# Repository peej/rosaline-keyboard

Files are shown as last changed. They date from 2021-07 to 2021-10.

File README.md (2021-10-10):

# Rosaline - Through-hole 40% keyboard PCB for 60% cases

Rosaline is a 40% keyboard PCB using through-hole components for that visible component aesthetic.

The goal of this project is to build an all through-hole component 40% PCB that fits in a standard 60% tray mount case.

Inspired by the [Plaid](https://github.com/hsgw/plaid) and the [Romeo](https://github.com/coseyfannitutti/romeo).

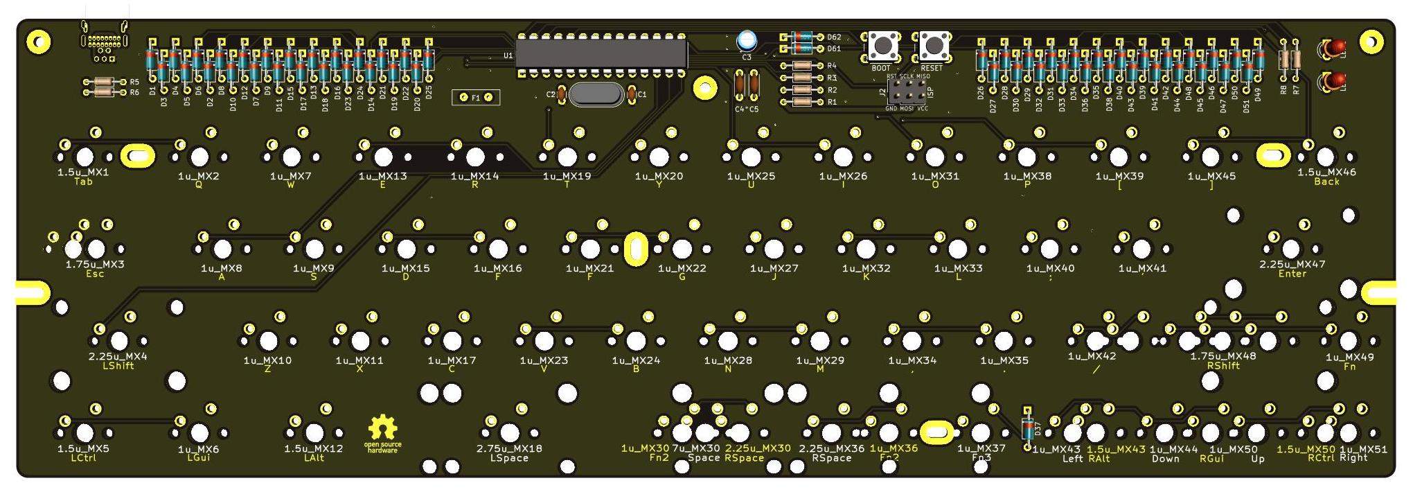
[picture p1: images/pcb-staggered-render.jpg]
PCB staggered render


* Designed to be easy to build with minimal soldering experience.
* All through-hole components, no SMD soldering required.
* Get that visible component aesthetic in a standard 60% tray-mount case.
* Staggered and ortholinear varieties.
* Supports both USB Mini and USB-C.

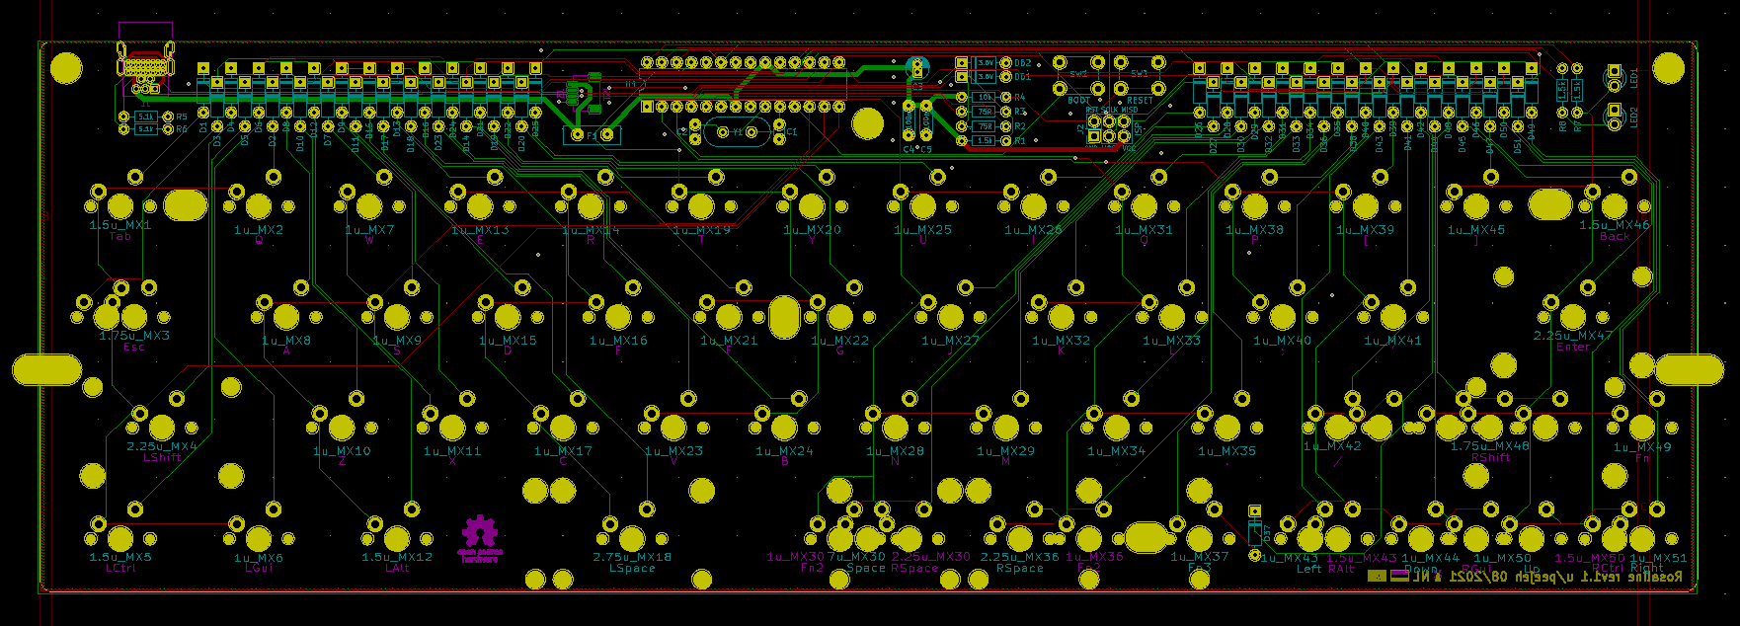
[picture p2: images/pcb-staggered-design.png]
PCB staggered design


The layout is a number row-less 60% layout with split spacebar or 7u bottom row and split right shift. An arrow cluster layout is also supported by moving the right shift.

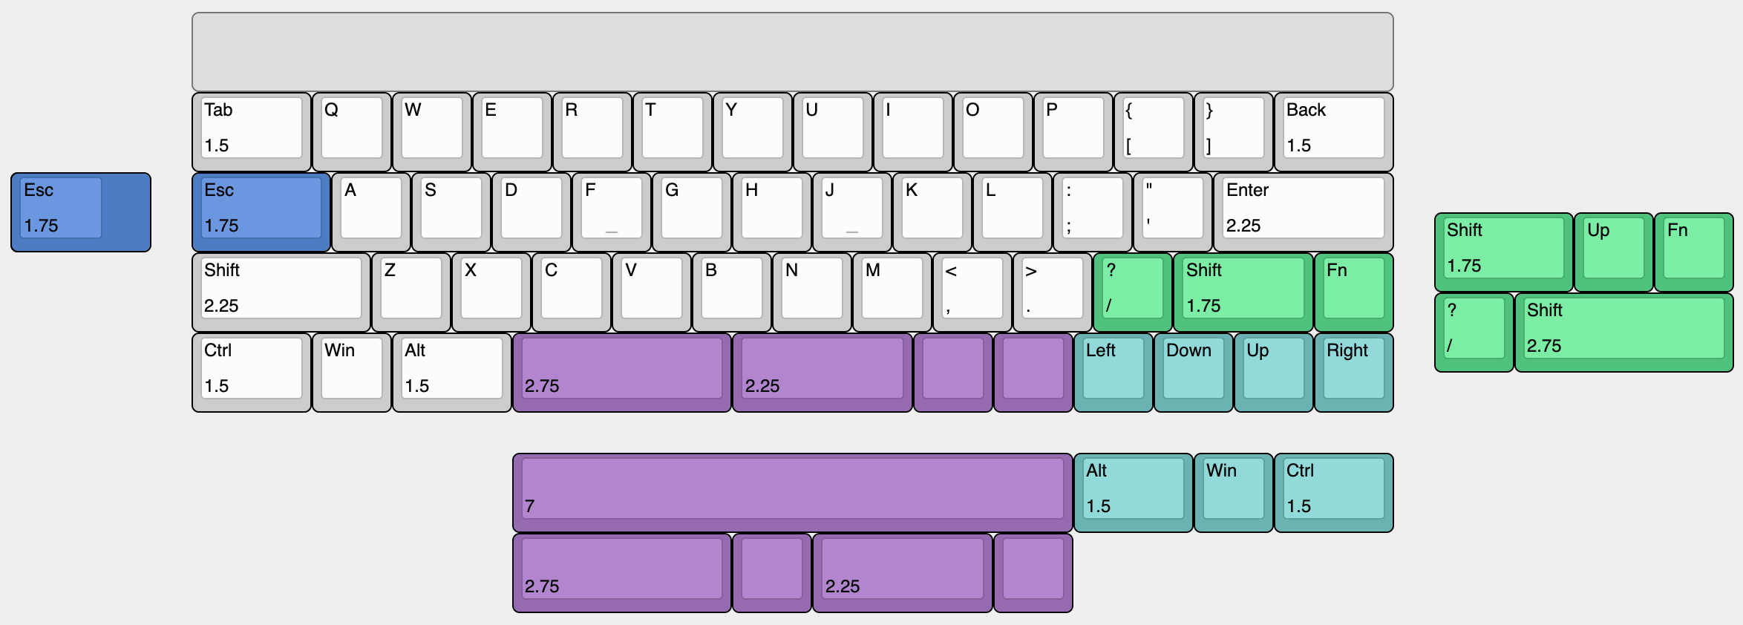
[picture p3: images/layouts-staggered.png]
Supported staggered layouts


# Ordering parts

PCBs can be manufactuered by a variety of online PCB fabricators. You can use [PCBShopper](https://pcbshopper.com/) to search for the best price.

# Construction

Solder all the components onto the top side of the PCB except the USB connector which should be on the back of the board. Leave the larger components until last so that the board will lie flat upsidedown while you solder the resistors and capacitors.

Take care to put the correct value resistors and capacitors in the correct places, the values are written on the silkmask along with the component reference. If you are unsure about the value of a resistor, check it with a multimeter.

Ensure that polarised components (diodes, LEDs, electrolytic capacitor (C3), IC socket) are in the correct orientation. The square pad is for the negative side of the component; for a diode this means the side with the black stripe; for LEDs and C3 the short leg is the cathode and goes in the square pad.

# Firmware

Firmware has not been merged into QMK upstream as of yet.

## Matrix information

If you are building your own firmware, the following matrix information will be useful to you:

| Configuration | Value |
|---|---|
| MATRIX_ROWS | 7 |
| MATRIX_COLS | 8 |
| MATRIX_ROW_PINS | C0, B5, B4, B3, B2, B1, C3 |
| MATRIX_COL_PINS | B0, D7, D6, C2, D4, D1, D0, C1 |
| DIODE_DIRECTION | COL2ROW |

# Component cover

Cut a piece of 2mm thick acrylic to size (285x19mm) and drill 3 m2 holes for the standoffs. Use the PCB as a guide for the hole positions.

Affix the 3 standoffs to the PCB with screws from underneath the PCB. Use the remaining 3 screws to attach the acrylic to the top of the standoffs.

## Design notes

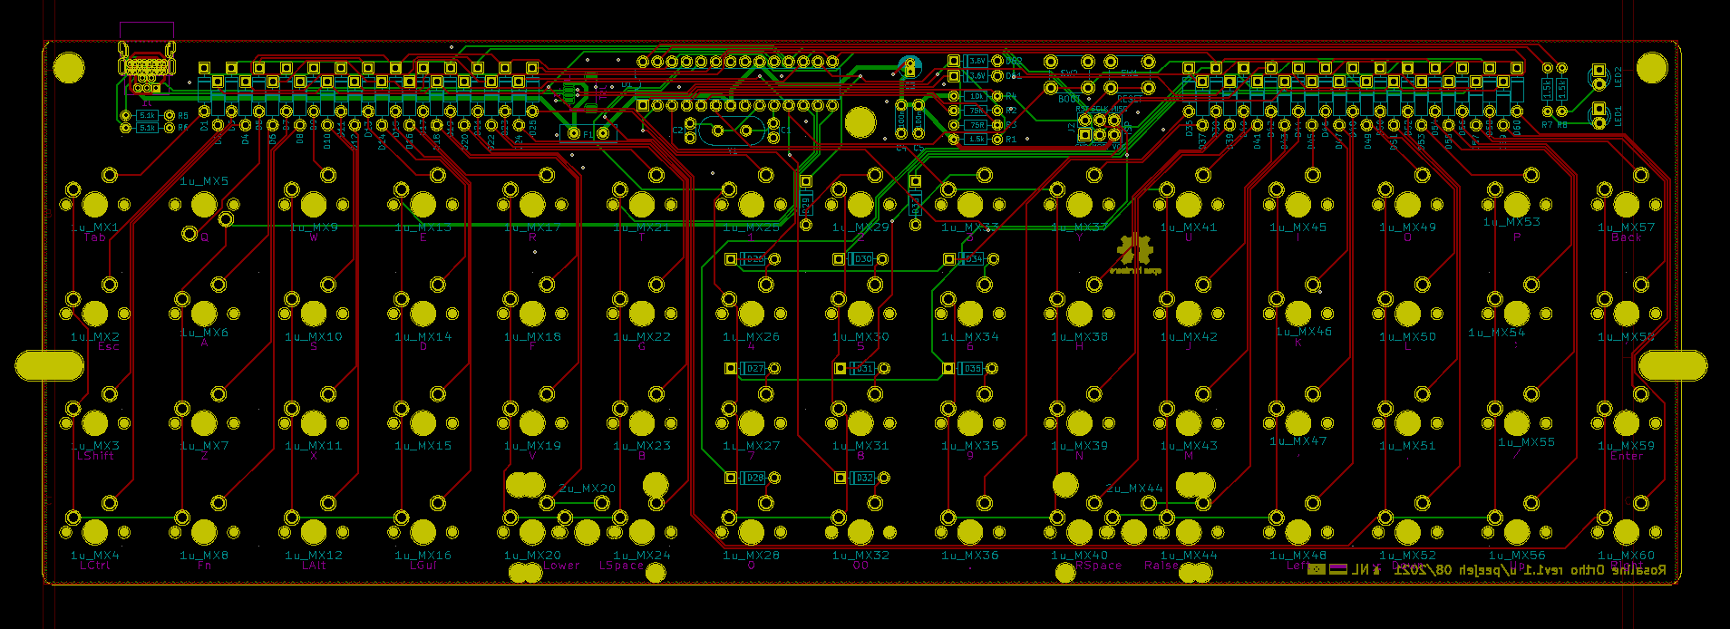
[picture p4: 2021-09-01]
images/pcb-ortho-design.png

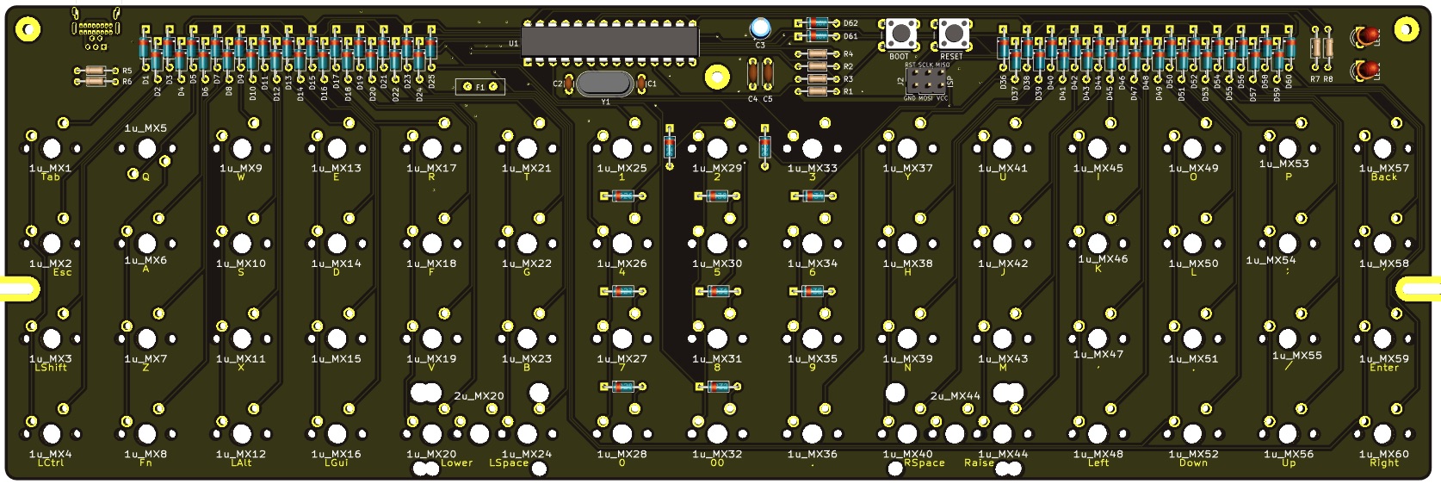
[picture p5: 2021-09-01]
images/pcb-ortho-render.jpg

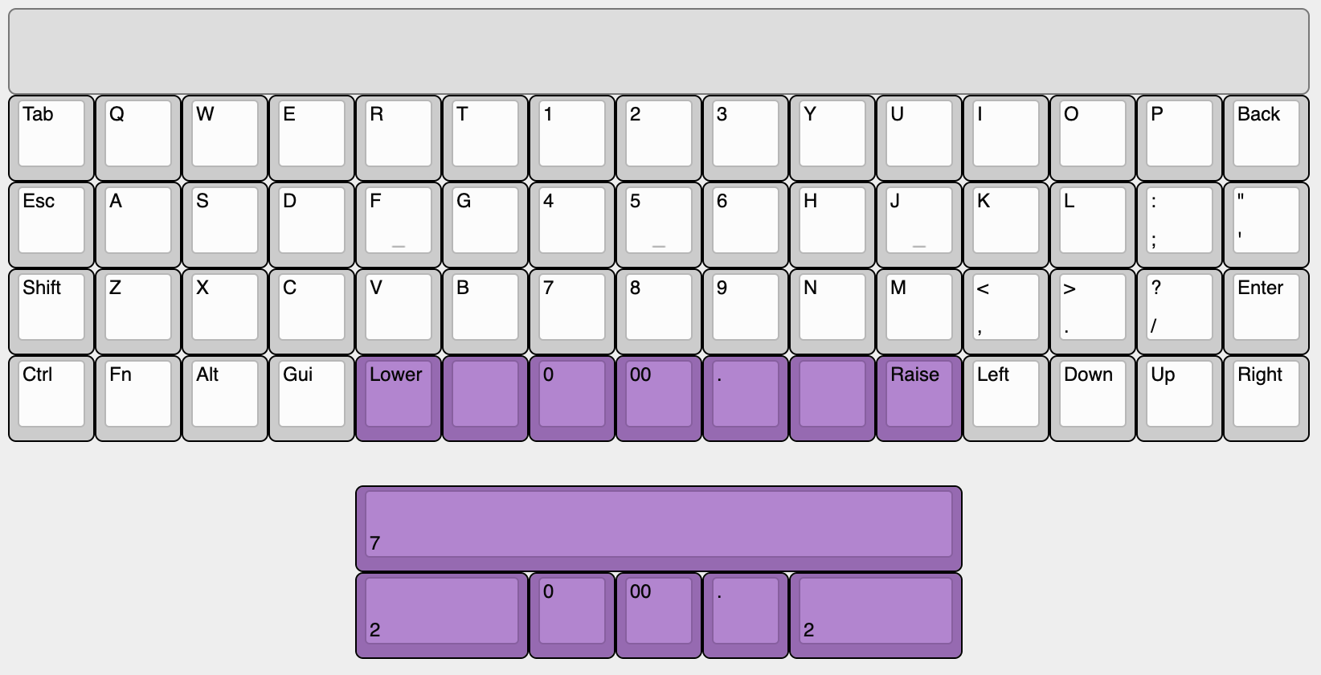
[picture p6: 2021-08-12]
images/layouts-ortho.png

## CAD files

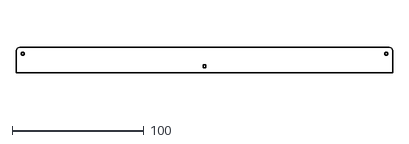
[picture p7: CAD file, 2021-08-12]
cover/cover.dxf
285.3 x 19.1

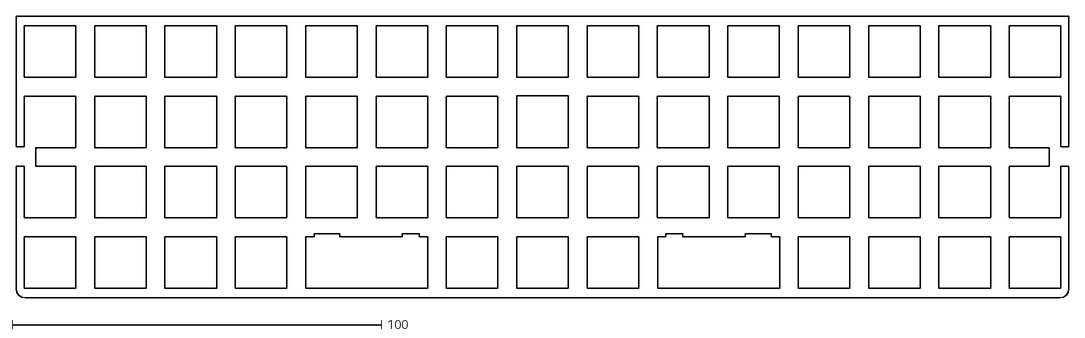
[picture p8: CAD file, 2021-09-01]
plate/plate-ortho.dxf
285.0 x 76.2

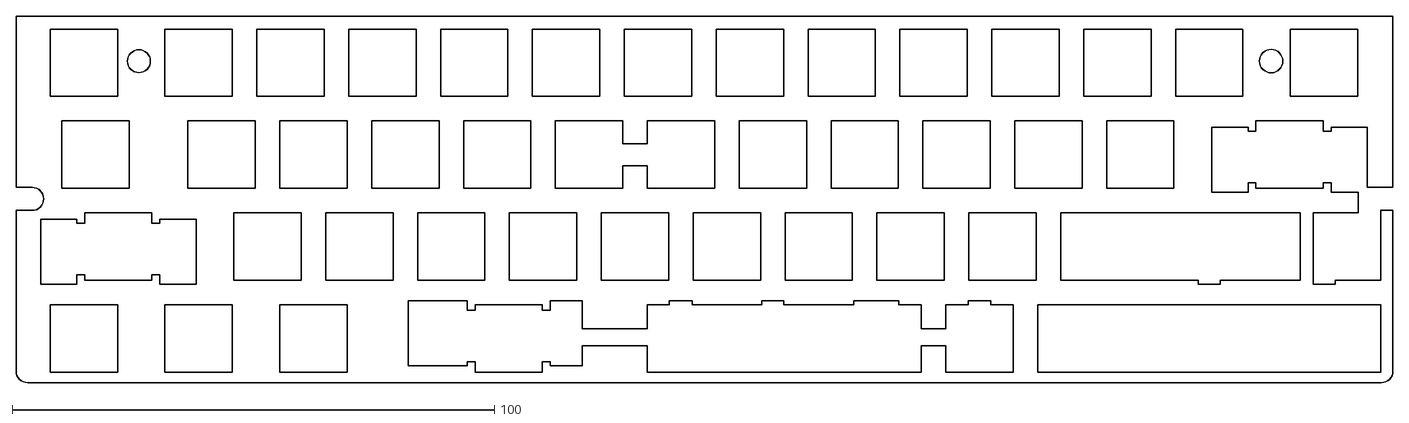
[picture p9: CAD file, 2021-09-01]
plate/plate.dxf
285.5 x 76.0

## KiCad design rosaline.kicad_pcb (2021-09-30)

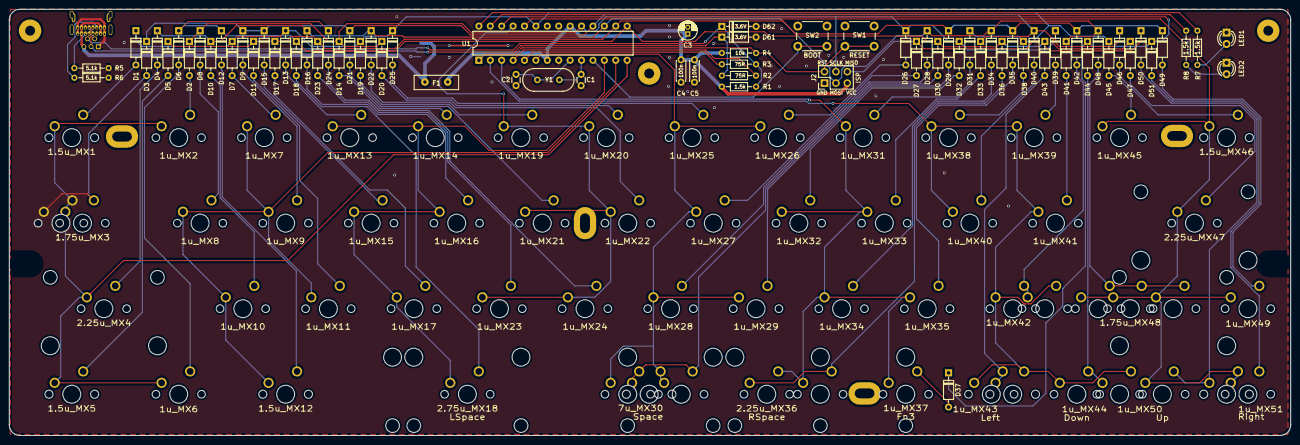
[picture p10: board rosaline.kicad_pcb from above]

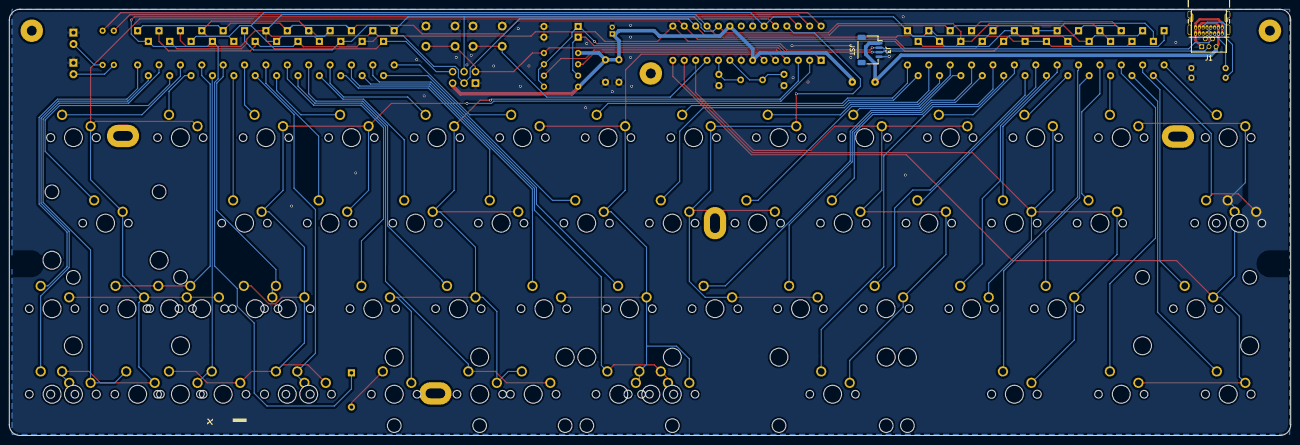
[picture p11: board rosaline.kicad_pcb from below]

Board: 2 copper layers, 285.4 x 94.9 mm, 148 parts (3 on the bottom side), 83 nets.

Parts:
1.5u_MX1: Tab; MX_PCB_150H
1.5u_MX5: LCtrl; MX_PCB_150H
1.5u_MX12: LAlt; MX_PCB_150H
1.5u_MX43: RAlt; MX_PCB_150H
1.5u_MX46: Back; MX_PCB_150H
1.5u_MX50: RCtrl; MX_PCB_150H
1.75u_MX3: Esc; MX_PCB_175H
1.75u_MX42, 1.75u_MX48: RShift; MX_PCB_175H
1u2_MX44: RGui; MX
1u_MX2: Q; MX
1u_MX6: LGui; MX
1u_MX7: W; MX
1u_MX8: A; MX
1u_MX9: S; MX
1u_MX10: Z; MX
1u_MX11: X; MX
1u_MX13: E; MX
1u_MX14: R; MX
1u_MX15: D; MX
1u_MX16, 1u_MX21: F; MX
1u_MX17: C; MX
1u_MX19: T; MX
1u_MX20: Y; MX
1u_MX22: G; MX
1u_MX23: V; MX
1u_MX24: B; MX
1u_MX25: U; MX
1u_MX26: I; MX
1u_MX27: J; MX
1u_MX28: N; MX
1u_MX29: M; MX
1u_MX30, 1u_MX36: Fn2; MX
1u_MX31: O; MX
1u_MX32: K; MX
1u_MX33: L; MX
1u_MX34: ,; MX
1u_MX35: .; MX
1u_MX37: Fn3; MX
1u_MX38: P; MX
1u_MX39: [; MX
1u_MX40: ;; MX
1u_MX41: '; MX
1u_MX42: /; MX
1u_MX43: Left; MX
1u_MX44: Down; MX
1u_MX45: ]; MX
1u_MX48, 1u_MX50: Up; MX
1u_MX49: Fn; MX
1u_MX51: Right; MX
2.25u_MX4: LShift; MX_PCB_225H
2.25u_MX30, 2.25u_MX36: RSpace; MX_PCB_225B
2.25u_MX47: Enter; MX_PCB_225H
2.75u_MX18: LSpace; MX_PCB_275B
2.75u_MX48: RShift; MX_PCB_275H
7u_MX30: Space; MX_PCB_700H
C1, C2: 22p; C_Disc_D3.0mm_W1.6mm_P2.50mm
C3: 4.7u; CP_Radial_D4.0mm_P1.50mm
C4, C5: 100n; C_Disc_D4.3mm_W1.9mm_P5.00mm
D1, D2, D3, D4, D5, D6, D7, D8, D9, D10, D11, D12, D13, D14, D15, D16, D17, D18, D19, D20, D21, D22, D23, D24, D25, D26, D27, D28, D29, D30, D31, D32, D33, D34, D35, D36, D37, D38, D39, D40, D41, D42, D43, D44, D45, D46, D47, D48, D49, D50, D51: 1N4148; D_DO-35_SOD27_P7.62mm_Horizontal
D61, D62: 3.6V; D_DO-35_SOD27_P7.62mm_Horizontal
F1: 100mA; Fuse_Bourns_MF-RHT100
Flags: flags; Flags
H1, H2, H3: M2; MountingHole_M2
H4, H9: M2; MountingSlot_M2
H5, H6, H7, H8: M2; MountingFlex_M2
J1: USB; USB_Hybrid_THT
J2: AVR_ISP_6; PinHeader_2x03_P2.54mm_Vertical
J3: JST; JST_SH_SM04B-SRSS-TB_1x04-1MP_P1.00mm_Horizontal
LED1: RED; LED_D3.0mm
LED2: GREEN; LED_D3.0mm
OSHW: OSHW-Logo_7.5x8mm_Copper
R1, R7, R8: 1.5k; R_Axial_DIN0204_L3.6mm_D1.6mm_P7.62mm_Horizontal
R2, R3: 75R; R_Axial_DIN0204_L3.6mm_D1.6mm_P7.62mm_Horizontal
R4: 10k; R_Axial_DIN0204_L3.6mm_D1.6mm_P7.62mm_Horizontal
R5, R6: 5.1k; R_Axial_DIN0204_L3.6mm_D1.6mm_P7.62mm_Horizontal
SW1: RESET; SW_PUSH_6mm
SW2: BOOT; SW_PUSH_6mm
U1: ATMEGA328-PU; DIP-28_W7.62mm
Y1: 16MHz; Crystal_HC49-4H_Vertical
stepped_MX3: Esc; MX

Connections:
+5V: C3.1, C4.1, C5.1, F1.2, J2.5, R1.2, R4.1, U1.7, U1.20
/COL0: 1.5u_MX1.2, 1.5u_MX5.2, 1.75u_MX3.2, 1u_MX2.2, 1u_MX6.2, 2.25u_MX4.2, U1.14, stepped_MX3.1
/COL1: 1.5u_MX12.2, 1u_MX7.2, 1u_MX8.2, 1u_MX9.2, 1u_MX10.2, 1u_MX11.2, U1.13
/COL2: 1u_MX13.2, 1u_MX14.2, 1u_MX15.2, 1u_MX16.2, 1u_MX17.2, 2.75u_MX18.2, U1.12
/COL3: 1u_MX19.2, 1u_MX20.2, 1u_MX21.2, 1u_MX22.2, 1u_MX23.2, 1u_MX24.2, U1.25
/COL4: 1u_MX25.2, 1u_MX26.2, 1u_MX27.2, 1u_MX28.2, 1u_MX29.2, 1u_MX30.2, 2.25u_MX30.2, 7u_MX30.1, U1.6
/COL5: 1u_MX31.2, 1u_MX32.2, 1u_MX33.2, 1u_MX34.2, 1u_MX35.2, 1u_MX36.2, 1u_MX37.2, 2.25u_MX36.1, U1.3
/COL6: 1.5u_MX43.1, 1.75u_MX42.1, 1u2_MX44.1, 1u_MX38.2, 1u_MX39.2, 1u_MX40.2, 1u_MX41.2, 1u_MX42.2, 1u_MX43.2, 1u_MX44.2, U1.2
/COL7: 1.5u_MX46.2, 1.5u_MX50.1, 1.75u_MX48.2, 1u_MX45.2, 1u_MX48.2, 1u_MX49.2, 1u_MX50.2, 1u_MX51.2, 2.25u_MX47.2, 2.75u_MX48.2, U1.24
/LED1: R7.1, U1.28
/LED2: R8.1, U1.27
/RESET: J2.2, R4.2, SW1.1, U1.1
/ROW0: D1.1, D7.1, D13.1, D19.1, D25.1, D31.1, D38.1, D45.1, U1.23
/ROW1: D2.1, D8.1, D14.1, D20.1, D26.1, D32.1, D39.1, D46.1, J2.4, U1.19
/ROW2: D3.1, D9.1, D15.1, D21.1, D27.1, D33.1, D40.1, D47.1, J2.6, U1.18
/ROW3: D4.1, D10.1, D16.1, D22.1, D28.1, D34.1, D41.1, D48.1, J2.3, U1.17
/ROW4: D5.1, D11.1, D17.1, D23.1, D29.1, D35.1, D42.1, D49.1, U1.16
/ROW5: D6.1, D12.1, D18.1, D24.1, D30.1, D36.1, D43.1, D50.1, U1.15
/ROW6: D37.1, D44.1, D51.1, U1.26
/USB_D+: R2.2, U1.4
/USB_D-: R3.2, U1.5
GND: C1.2, C2.2, C3.2, C4.2, C5.2, D61.2, D62.2, J1.GND, J2.1, J3.4, LED1.1, LED2.1, R5.1, R6.1, SW1.2, SW2.2, U1.8, U1.22
unnamed: 1.5u_MX1.1, D1.2
unnamed: 1.5u_MX5.1, D5.2
unnamed: 1.5u_MX12.1, D12.2
unnamed: 1.5u_MX43.2, 1u_MX43.1, D43.2
unnamed: 1.5u_MX46.1, D46.2
unnamed: 1.5u_MX50.2, 1u_MX50.1, D50.2
unnamed: 1.75u_MX3.1, D3.2, stepped_MX3.2
unnamed: 1.75u_MX42.2, 1u_MX42.1, D42.2
unnamed: 1.75u_MX48.1, 1u_MX48.1, 2.75u_MX48.1, D48.2
unnamed: 1u2_MX44.2, 1u_MX44.1, D44.2
unnamed: 1u_MX2.1, D2.2
unnamed: 1u_MX6.1, D6.2
unnamed: 1u_MX7.1, D7.2
unnamed: 1u_MX8.1, D8.2
unnamed: 1u_MX9.1, D9.2
unnamed: 1u_MX10.1, D10.2
unnamed: 1u_MX11.1, D11.2
unnamed: 1u_MX13.1, D13.2
unnamed: 1u_MX14.1, D14.2
unnamed: 1u_MX15.1, D15.2
unnamed: 1u_MX16.1, D16.2
unnamed: 1u_MX17.1, D17.2
unnamed: 1u_MX19.1, D19.2
unnamed: 1u_MX20.1, D20.2
unnamed: 1u_MX21.1, D21.2
unnamed: 1u_MX22.1, D22.2
unnamed: 1u_MX23.1, D23.2
unnamed: 1u_MX24.1, D24.2
unnamed: 1u_MX25.1, D25.2
unnamed: 1u_MX26.1, D26.2
unnamed: 1u_MX27.1, D27.2
unnamed: 1u_MX28.1, D28.2
unnamed: 1u_MX29.1, D29.2
unnamed: 1u_MX30.1, 2.25u_MX30.1, 7u_MX30.2, D30.2
unnamed: 1u_MX31.1, D31.2
unnamed: 1u_MX32.1, D32.2
unnamed: 1u_MX33.1, D33.2
unnamed: 1u_MX34.1, D34.2
unnamed: 1u_MX35.1, D35.2
unnamed: 1u_MX36.1, 2.25u_MX36.2, D36.2
unnamed: 1u_MX37.1, D37.2
unnamed: 1u_MX38.1, D38.2
unnamed: 1u_MX39.1, D39.2
unnamed: 1u_MX40.1, D40.2
unnamed: 1u_MX41.1, D41.2
unnamed: 1u_MX45.1, D45.2
unnamed: 1u_MX49.1, D49.2
unnamed: 1u_MX51.1, D51.2
unnamed: 2.25u_MX4.1, D4.2
unnamed: 2.25u_MX47.1, D47.2
unnamed: 2.75u_MX18.1, D18.2
unnamed: C1.1, U1.10, Y1.2
unnamed: C2.1, U1.9, Y1.1
unnamed: D61.1, J1.D+, J3.3, R2.1
unnamed: D62.1, J1.D-, J3.2, R1.1, R3.1
unnamed: F1.1, J1.V+, J3.1
unnamed: J1.CC1, R5.2
unnamed: J1.CC2, R6.2
unnamed: LED1.2, R7.2
unnamed: LED2.2, R8.2
unnamed: SW2.1, U1.11

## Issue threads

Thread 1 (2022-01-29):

VIA JSON

dayofdoom, 2022-01-29:
Hello,

I've been searching for the VIA.json file for this board but I cant' find it. Can you point me in the right direction?

Sent from my rosaline

peej, 2022-01-29:
Sorry, I hadn't realised I hadn't pushed it to my VIA fork: https://github.com/peej/keyboards/blob/rosaline/src/peej/rosaline/rosaline.json

dayofdoom, 2022-01-29:
Thanks for that, worked perfect.

Drbacteria2, 2025-01-30:
Good morning Peej,

I am a long time lumberjack keyboard user and now I decided to try your Rosaline Stagged board.

I ordered plates and so on and everything fine. I loaded into the processor the .hex file that is posted on the VIA page and everything worked fine, I type with the predefined layout.

When I want to load the json file that is in this post in the via page, I get an error that attributes are missing and the keyboard does not load.

Can you take a look at the json code to see if everything is correct? my knowledge of programming is very limited...

On the other hand, when I connect the lumberjack to VIA direct, I get the keymap to adjust it to my taste directly.

Thanks in advance for all the work you do.

Translated with DeepL.com (free version)

peej, 2025-01-30:
Hi @Drbacteria2,

Very cool that you have built your own Rosaline and it works. Congratulations.

The JSON file was for VIA v2 but the VIA website now uses the v3 protocol. I have hopefully created new JSON that should work with v3: https://github.com/peej/keyboards/blob/rosaline/v3/peej/rosaline/rosaline.json

Drbacteria2, 2025-01-31:
Good morning again,

Thank you very much for the json update. It works perfectly on the VIA site now.

This is the first Rosaline I made and I have four others to assemble, I find it a very aesthetic keyboard and very easy to use. I will order another five Rosaline ortho's to try as I am very used to the Lumberjack.

Your PCBs are perfect for me as I find them aesthetically pleasing and very easy to use. I repeat my thanks for making them.

PS: I have the lumberjack mounted with o-ring in an ash wood case, the sound with this setup is great.
Could you make a version of the Rosaline with the o-ring mounted PCBs?
I would be very grateful to you as I have several cases to use with this setup.

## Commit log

2021-05-26 Change bottom row layout options
    [juliet.kicad_pcb, juliet.sch]
2021-05-27 Add component cover DXF
    [cover.dxf]
2021-07-31 Switch bottom row stabilizer orientation
    [juliet.kicad_pcb]
2021-08-12 Add plate
    [plate.kicad_pcb]
2021-08-12 Add ortho variant
    [juliet-ortho.kicad_pcb, juliet-ortho.sch, plate-ortho.kicad_pcb]
2021-08-12 Add gerber files
    [juliet-Eco2_User.dxf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]
2021-08-12 Fix exported cover DXF file
    [cover.dxf]
2021-08-20 Fix overlapping trace on MX30
    [juliet-Eco2_User.dxf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]
2021-08-20 Add fmask layer to ortho plate
    [plate-ortho.kicad_pcb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]
2021-08-31 Rename project
    [plate.kicad_pcb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]
2021-09-01 Update PCB renders
2021-09-01 Update plate files
    [plate-B_Cu.gbr, plate-B_Mask.gbr, plate-Edge_Cuts.gbr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]
2021-09-01 Fix broken trace on ortho PCB
    [rosaline-ortho-B_Cu.gbr, rosaline-ortho-B_Mask.gbr, rosaline-ortho-B_Paste.gbr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]
2021-09-30 Add stepped caps lock switch footprint
    [rosaline.kicad_pcb, rosaline.sch]
